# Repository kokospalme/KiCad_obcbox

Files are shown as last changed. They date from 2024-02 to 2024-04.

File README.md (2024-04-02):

# KiCad_obcbox
Hardware of the obcbox-project. This PCB is designed for a raspberry pi 3 B+ and an 0.96" OLED screen (be careful with the display-pinout!)
* Software (main): [java-BC](https://github.com/kokospalme/java-BC/tree/obcbox)
* Software (gui): [obcgui](https://github.com/kokospalme/obcgui/)
* Hardware (pcb): [KiCad_obcbox](https://github.com/kokospalme/KiCad_obcbox)
* Hardware (case): [grabcad](https://grabcad.com/library/obcbox-enclosure-v1-0-1)

# Status quo
<a href="">PCB_v0.2</a>
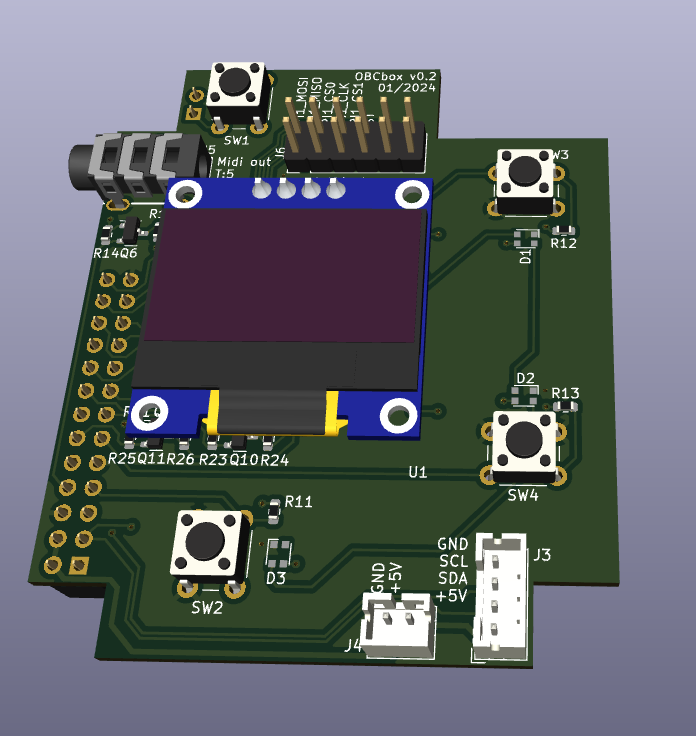
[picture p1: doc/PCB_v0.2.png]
PCB_v0.2

* [v0.2 is working](https://github.com/kokospalme/KiCad_obcbox/releases)

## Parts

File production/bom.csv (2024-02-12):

Designator | Footprint | Quantity | Value | LCSC Part #
D1, D2, D3 | LED_WS2812C-2020 | 3 | WS2812C | C965556
J1 | PinSocket_2x13_P2.54mm_Vertical | 1 | RASPI
J2 | PinSocket_1x02_P2.54mm_Vertical | 1 | PI_RST
J3 | JST_PH_B4B-PH-K_1x04_P2.00mm_Vertical | 1 | I2C
J4 | JST_PH_B2B-PH-K_1x02_P2.00mm_Vertical | 1 | PWR
J5 | C18167_BOOMELE_Audiojack_withoutTip | 1 | WS28A
J6 | PinHeader_2x06_P2.54mm_Vertical | 1 | GPIO
Q1, Q10, Q11, Q2, Q3, Q4, Q5, Q6, Q7, Q8, Q9 | SOT-23 | 11 | BSS138
R1, R10, R11, R12, R13, R14, R15, R16, R17, R18, R19, R2, R20, R21, R22, R23, R24, R25, R26, R3, R4, R5, R6, R7, R8, R9 | 0603 | 26 | 10k
SW1 | SW_PUSH_6mm_H4.3mm | 1 | RST
SW2 | SW_PUSH_6mm_H4.3mm | 1 | MA
SW3 | SW_PUSH_6mm_H4.3mm | 1 | LAT_UP
SW4 | SW_PUSH_6mm_H4.3mm | 1 | LAT_DOWN
U1 | SSD1306_OLED-0.96-128x64_I2C | 1 | OLED_0.96-I2C

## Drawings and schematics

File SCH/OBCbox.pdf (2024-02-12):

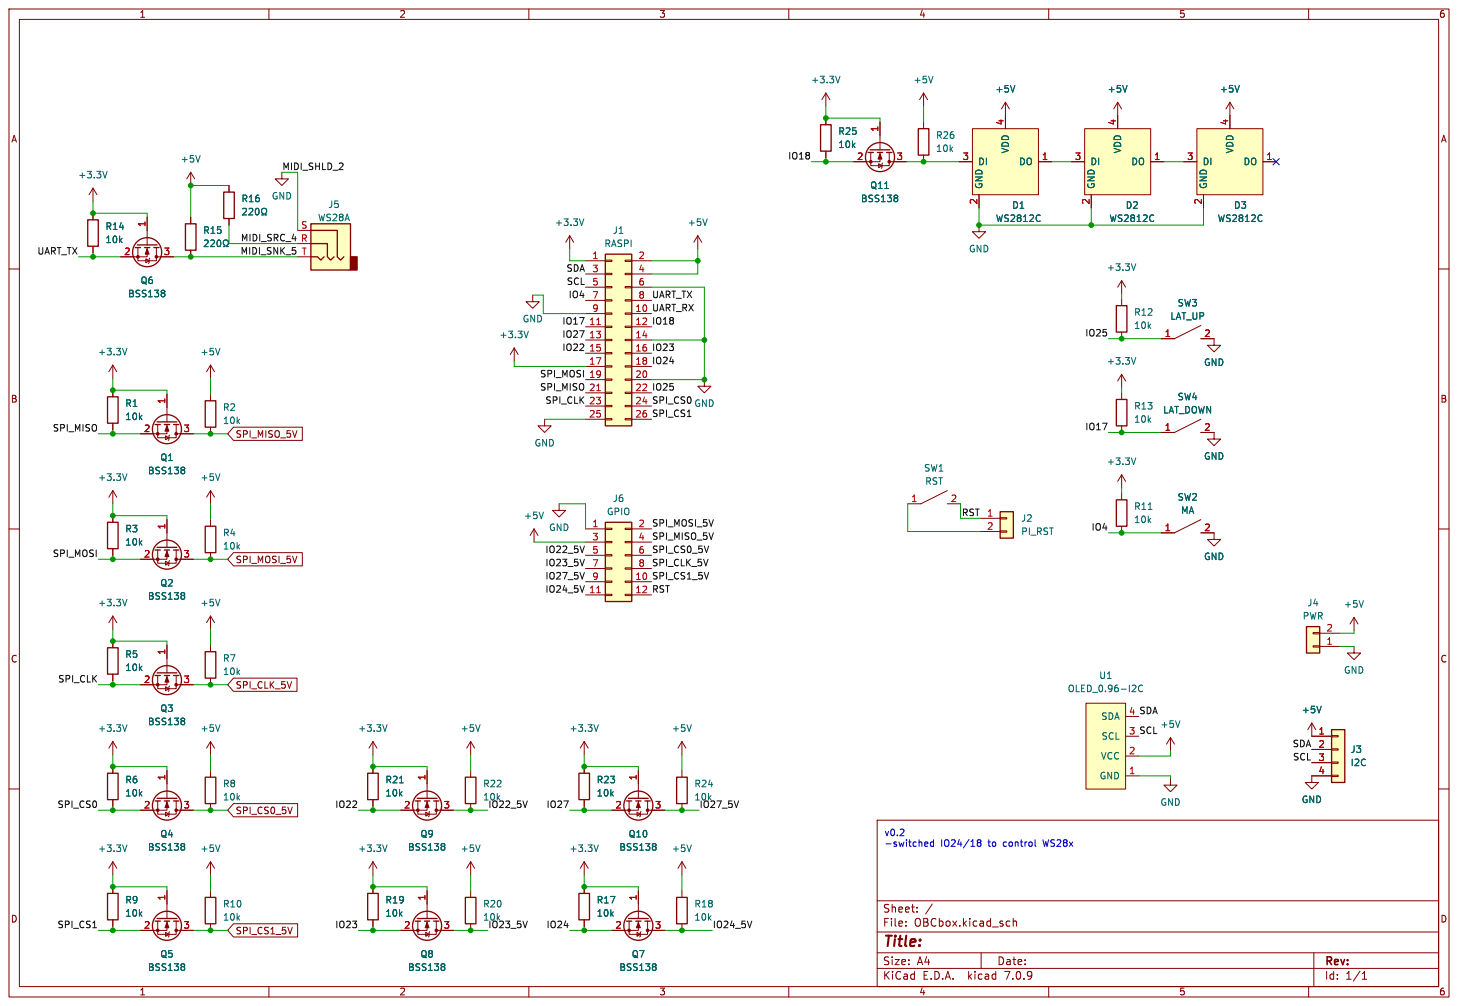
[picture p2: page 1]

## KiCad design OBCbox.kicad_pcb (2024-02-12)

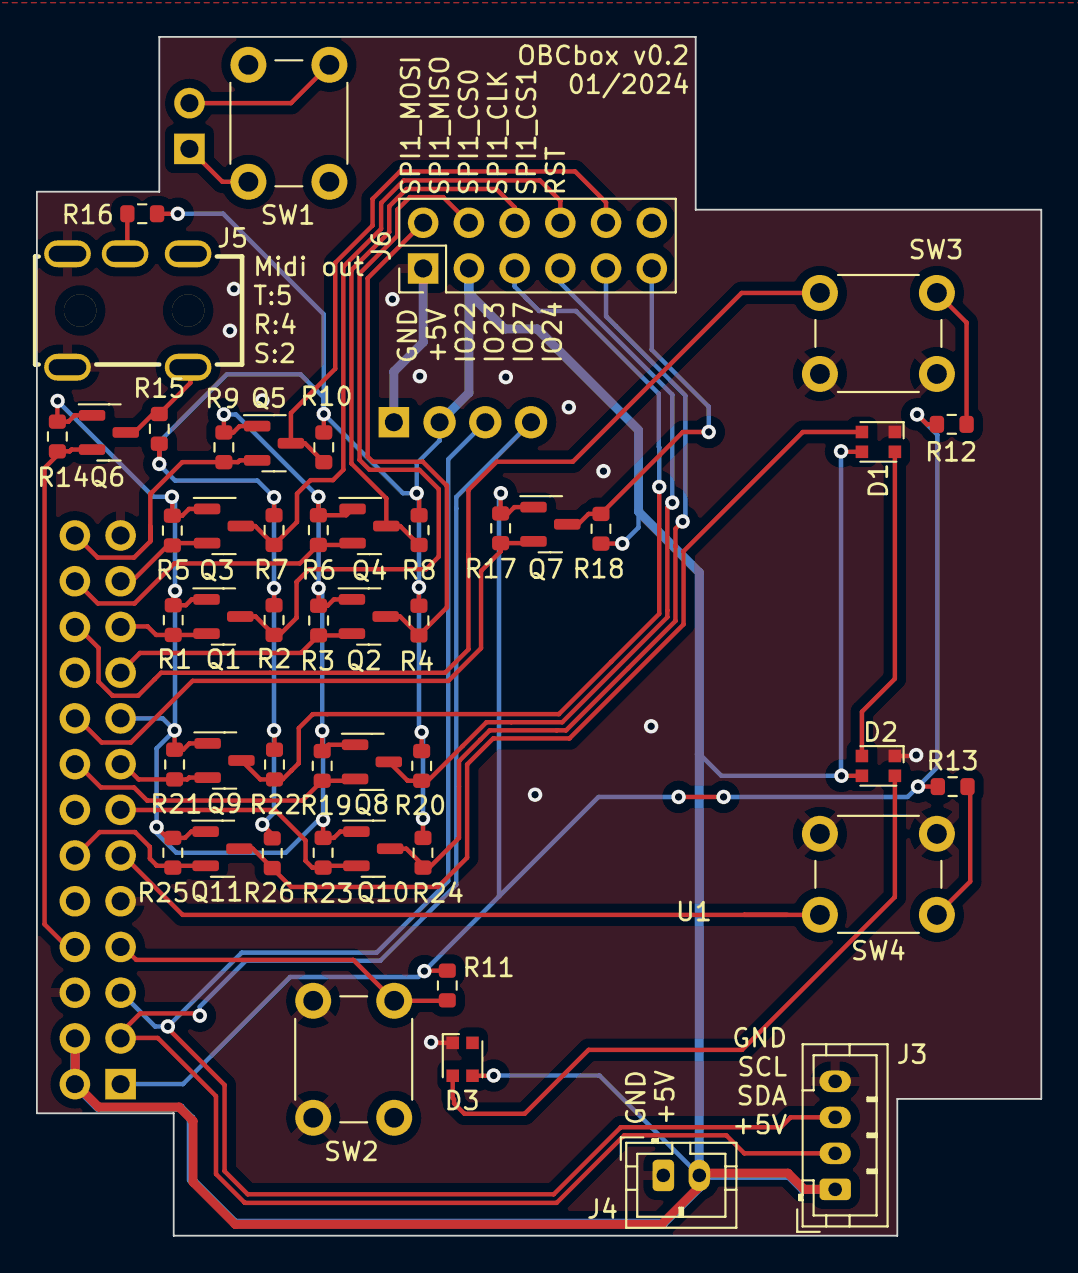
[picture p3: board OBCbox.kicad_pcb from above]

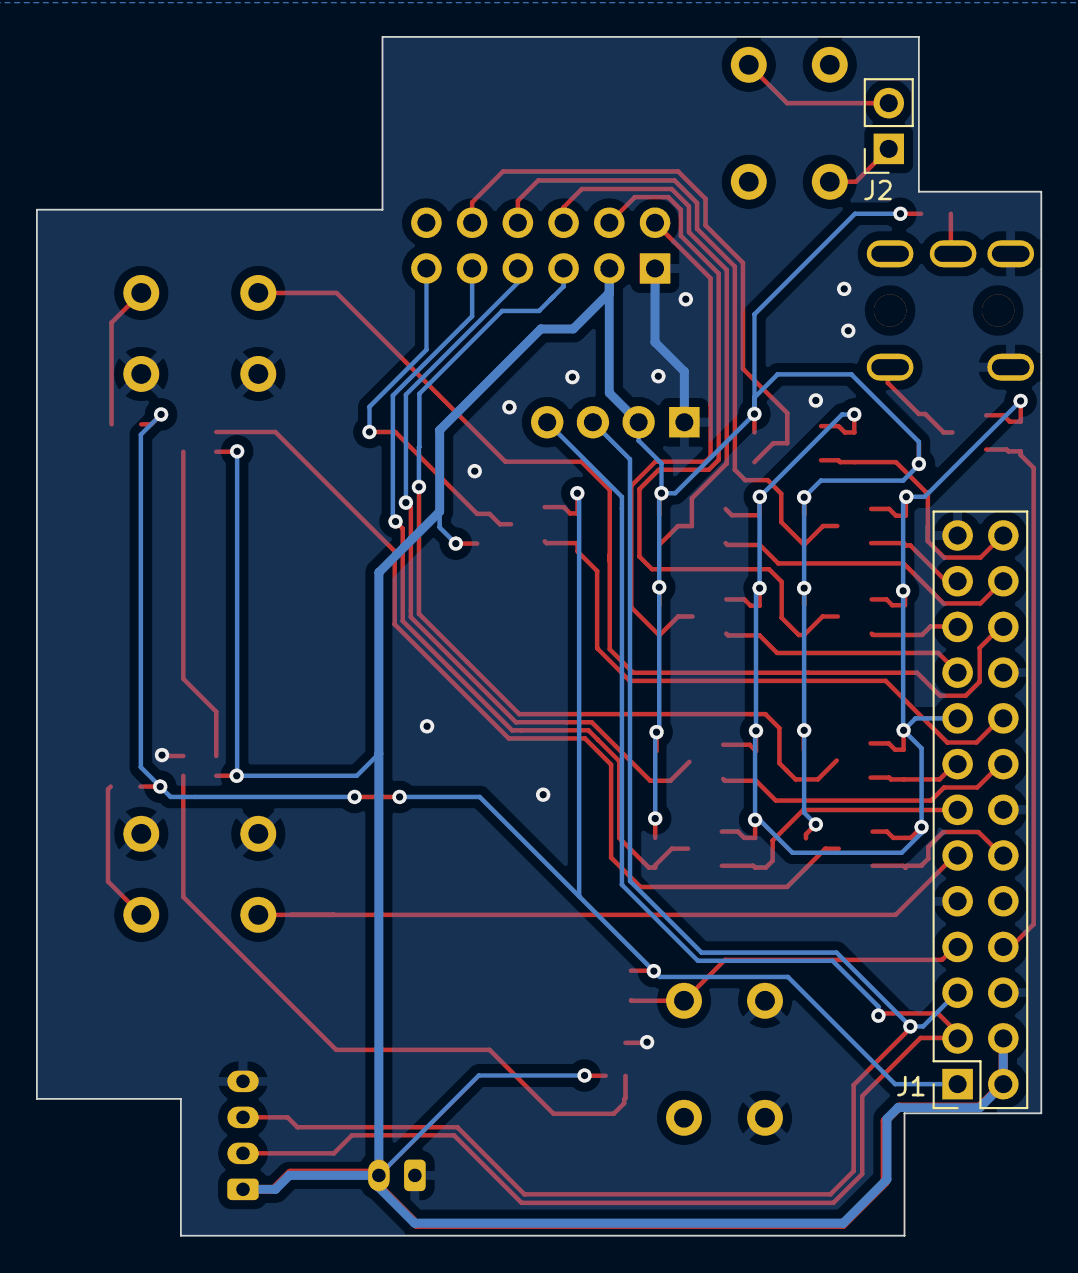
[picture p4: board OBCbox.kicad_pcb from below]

Board: 2 copper layers, 55.8 x 66.6 mm, 51 parts (2 on the bottom side), 35 nets.

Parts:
D1, D2, D3: WS2812C; LED_WS2812C-2020
J1: RASPI; PinSocket_2x13_P2.54mm_Vertical
J2: PI_RST; PinSocket_1x02_P2.54mm_Vertical
J3: I2C; JST_PH_B4B-PH-K_1x04_P2.00mm_Vertical
J4: PWR; JST_PH_B2B-PH-K_1x02_P2.00mm_Vertical
J5: WS28A; C18167_BOOMELE_Audiojack_withoutTip
J6: GPIO; PinHeader_2x06_P2.54mm_Vertical
Q1, Q2, Q3, Q4, Q5, Q6, Q7, Q8, Q9, Q10, Q11: BSS138; SOT-23
R1, R2, R3, R4, R5, R6, R7, R8, R9, R10, R11, R12, R13, R14, R17, R18, R19, R20, R21, R22, R23, R24, R25, R26: 10k; R_0603_1608Metric
R15, R16: 220Ω; R_0603_1608Metric
SW1: RST; SW_PUSH_6mm_H4.3mm
SW2: MA; SW_PUSH_6mm_H4.3mm
SW3: LAT_UP; SW_PUSH_6mm_H4.3mm
SW4: LAT_DOWN; SW_PUSH_6mm_H4.3mm
U1: OLED_0.96-I2C; SSD1306_OLED-0.96-128x64_I2C

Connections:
+3.3V: J1.1, J1.17, Q1.1 (G), Q2.1 (G), Q3.1 (G), Q4.1 (G), Q5.1 (G), Q6.1 (G), Q7.1 (G), Q8.1 (G), Q9.1 (G), Q10.1 (G), Q11.1 (G), R1.1, R3.1, R5.1, R6.1, R9.1, R11.1, R12.1, R13.1, R14.1, R17.1, R19.1, R21.1, R23.1, R25.1
+5V: D1.4 (VDD), D2.4 (VDD), D3.4 (VDD), J1.2, J1.4, J3.1, J4.2, J6.3, R2.1, R4.1, R7.1, R8.1, R10.1, R15.1, R16.1, R18.1, R20.1, R22.1, R24.1, R26.1, U1.2 (VCC)
/IO4: J1.7, R11.2, SW2.1
/IO17: J1.11, R13.2, SW4.1
/IO18: J1.12, Q11.2 (S), R25.2
/IO22: J1.15, Q9.2 (S), R21.2
/IO22_5V: J6.5, Q9.3 (D), R22.2
/IO23: J1.16, Q8.2 (S), R19.2
/IO23_5V: J6.7, Q8.3 (D), R20.2
/IO24: J1.18, Q7.2 (S), R17.2
/IO24_5V: J6.11, Q7.3 (D), R18.2
/IO25: J1.22, R12.2, SW3.1
/IO27: J1.13, Q10.2 (S), R23.2
/IO27_5V: J6.9, Q10.3 (D), R24.2
/MIDI_SNK_5: J5.T, Q6.3 (D), R15.2
/MIDI_SRC_4: J5.R, R16.2
/RST: J2.1, J6.12, SW1.2
/SCL: J1.5, J3.3, U1.3 (SCL)
/SDA: J1.3, J3.2, U1.4 (SDA)
/SPI_CLK: J1.23, Q3.2 (S), R5.2
/SPI_CS0: J1.24, Q4.2 (S), R6.2
/SPI_CS1: J1.26, Q5.2 (S), R9.2
/SPI_MISO: J1.21, Q1.2 (S), R1.2
/SPI_MOSI: J1.19, Q2.2 (S), R3.2
/UART_TX: J1.8, Q6.2 (S), R14.2
GND: D1.2 (GND), D2.2 (GND), D3.2 (GND), J1.6, J1.9, J1.14, J1.20, J1.25, J3.4, J4.1, J5.S, J6.1, SW2.2, SW3.2, SW4.2, U1.1 (GND)
unnamed: D1.3 (DI), Q11.3 (D), R26.2
unnamed: D1.1 (DO), D2.3 (DI)
unnamed: D2.1 (DO), D3.3 (DI)
unnamed: J2.2, SW1.1
SPI_CLK_5V: J6.8, Q3.3 (D), R7.2
SPI_CS0_5V: J6.6, Q4.3 (D), R8.2
SPI_CS1_5V: J6.10, Q5.3 (D), R10.2
SPI_MISO_5V: J6.4, Q1.3 (D), R2.2
SPI_MOSI_5V: J6.2, Q2.3 (D), R4.2

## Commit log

2024-02-12 v0.2 bugfixes
    [OBCbox.kicad_pcb, OBCbox.kicad_sch, bom.csv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]
2024-02-12 update doc
    [bom.csv, designators.csv, positions.csv]
